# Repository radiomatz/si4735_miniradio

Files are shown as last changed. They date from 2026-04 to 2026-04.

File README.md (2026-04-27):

# si4735_miniradio
SI4735-D60 Circuit and Arduino Sketech for Building a SW/FM Radio with 150kHz..30MHz AM/SSB + 64-108MHz FM

<img src="pics/testcircuit.jpg>

### used Hardware
- Atmega 328P-PU with its internal 8 MHz
- SI4735-D60-GU
- LM386 Dip
- LM1117 3.3 Volts
- SMD Capacitors all 0805
- Elkos all tht, mnost low profile or layed flat
- Quartz 32k Clock Crystal

### Software needed
- Arduino Studio Version 2
- addon for MiniCore (support for single 328 Chips)
- tiny4k oled library and (6x8) font package

### some details
- i am using a 7.2V LiPo, which is directly connencted to the lm386 - it can have about 5-12V
- the mcu and the radio chip SI4735-D60-GU is driven with a LM1117-3.3 with 3.3V, that is important for the SI4735, and enough for an ATMEGA328

### some modifications (which will be in v2 circuit) are made after this circuit(v1):

- add a reset knob between pin 1 of atmega328-pu and gnd for programming from outside.
- insert a 1k2 resistor between pin 1 of lm386 and the 10µ c at pin 8, because gain of 50 is enough.
- my first circuit (the one with the case) i used sockets and plugs for programming outside, but i recommend to solder the AT328 directly and dont use the plugs on the circuit, instead use direct wires for getting more place in the case. Also i used another CA5 

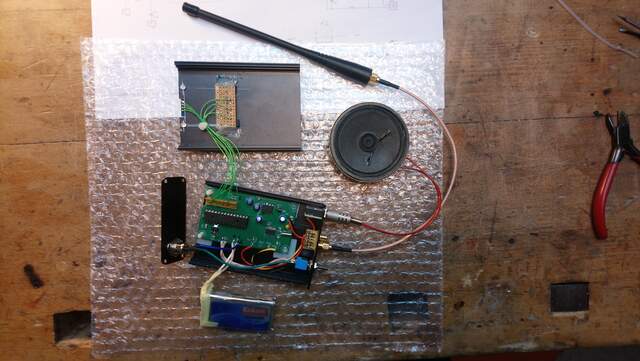
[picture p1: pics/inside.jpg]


### hints for using
- left button is "down", middle button is "mode", right button is "up"
- you have a preview of the mode right of the mode which has the star in front.
- frequency display has as suffix its step with a slash, also bfo 
- to lock, press up or down in lock mode; to unlock, use up and down simultaneous

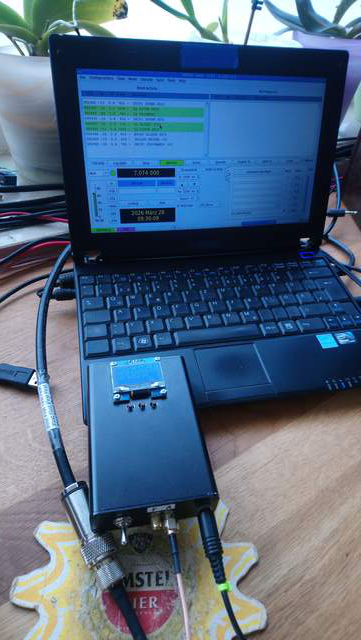
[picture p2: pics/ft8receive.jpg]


if you have any questions, feel free to ask me: dm2hr@darc.de

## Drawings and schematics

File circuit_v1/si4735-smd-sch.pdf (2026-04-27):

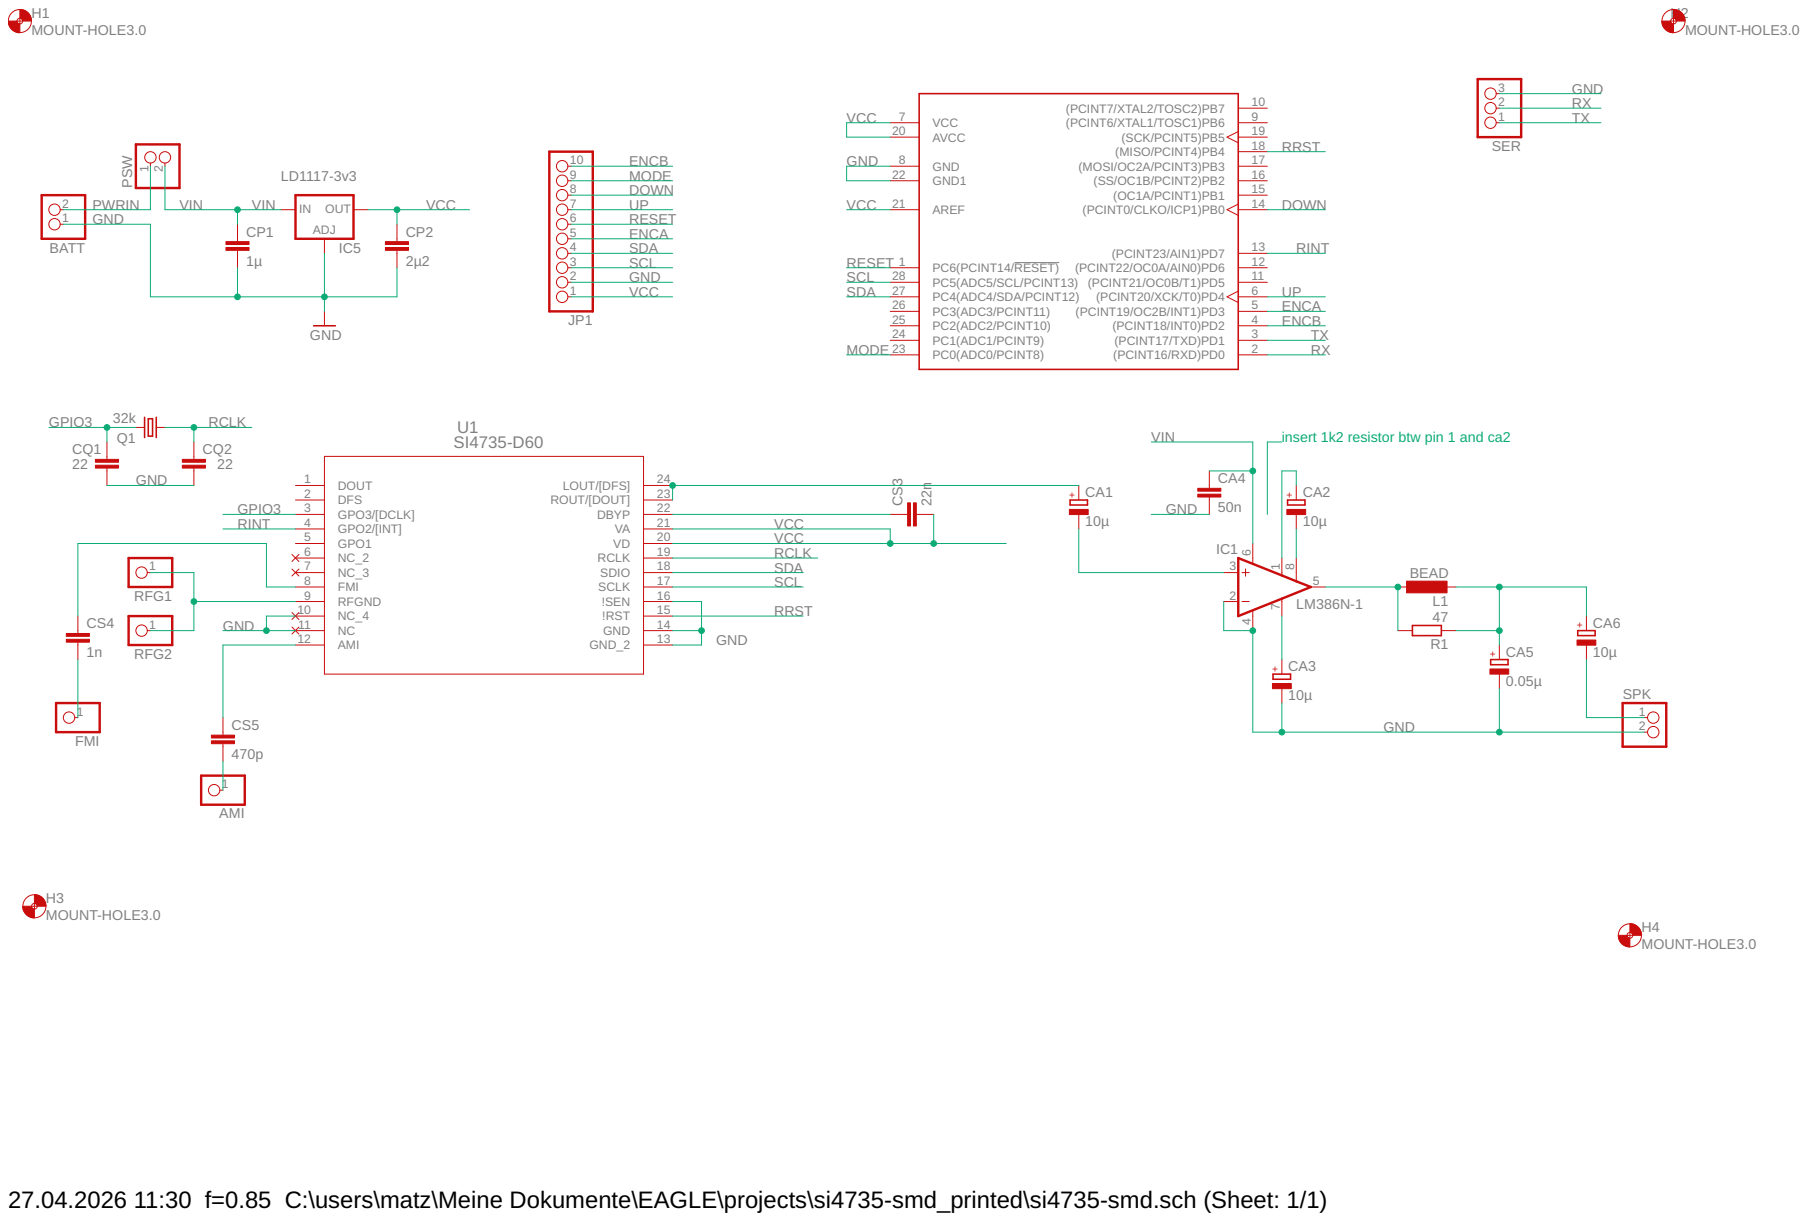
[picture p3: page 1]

insert 1k2 resistor btw pin 1 and ca2

27.04.2026 11:30 f=0.85 C:\users\matz\Meine Dokumente\EAGLE\projects\si4735-smd_printed\si4735-smd.sch (Sheet: 1/1)

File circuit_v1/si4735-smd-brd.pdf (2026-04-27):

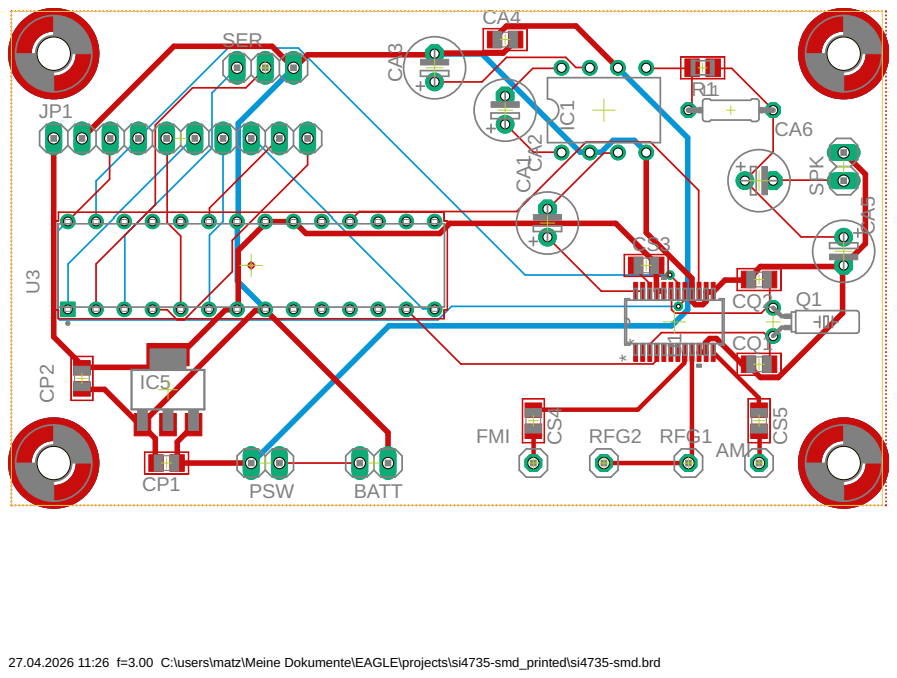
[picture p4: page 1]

27.04.2026 11:26 f=3.00 C:\users\matz\Meine Dokumente\EAGLE\projects\si4735-smd_printed\si4735-smd.brd

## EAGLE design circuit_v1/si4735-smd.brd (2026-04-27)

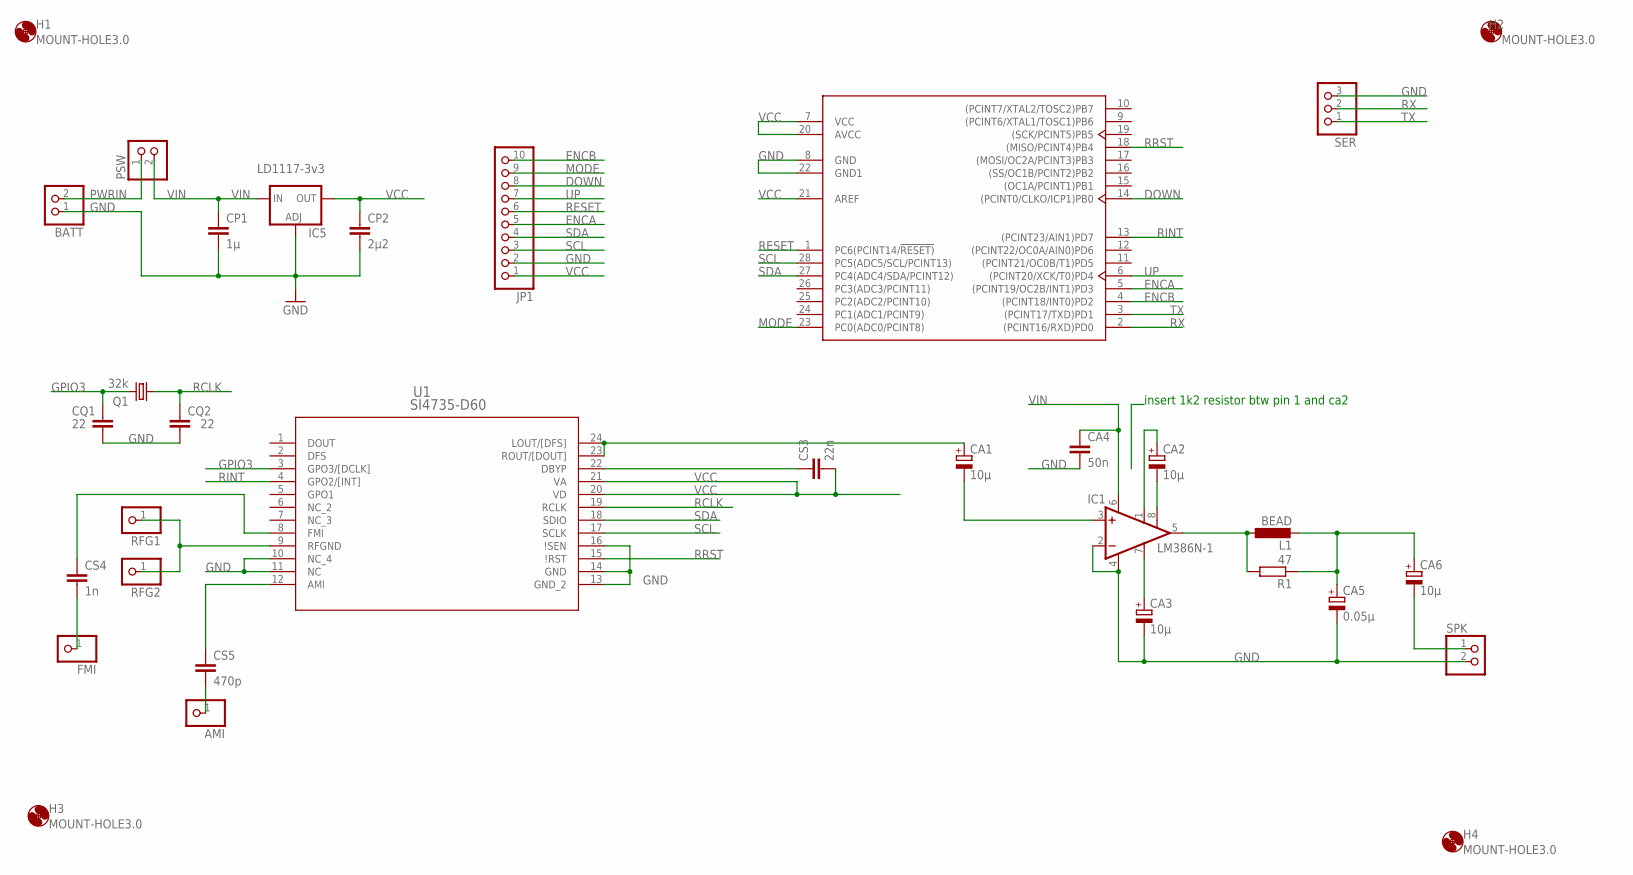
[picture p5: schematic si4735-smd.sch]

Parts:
AMI: PINHD-1X1; 1X01
BATT: PINHD-1X2; 1X02
CA1, CA2, CA3, CA6: 10µ; E2,5-6
CA4: 50n; C0805
CA5: 0.05µ; E2,5-6
CP1: 1µ; C0805
CP2: 2µ2; C0805
CQ1, CQ2: 22; C0805
CS3: 22n; C0805
CS4: 1n; C0805
CS5: 470p; C0805
FMI: PINHD-1X1; 1X01
H1, H2, H3, H4: MOUNT-HOLE3.0; 3,0
IC1: LM386N-1; DIL08
IC5: LD1117-3v3; SOT223
JP1: PINHD-1X10; 1X10
L1: BEAD; 0204/7
PSW: PINHD-1X2; 1X02
Q1: 32k; TC26H
R1: 47; M0805
RFG1, RFG2: PINHD-1X1; 1X01
SER: PINHD-1X3; 1X03
SPK: PINHD-1X2; 1X02
U1: SI4735-D60; SSOP24_SIL-M
U3: ATMEGA328P-PU; DIP-28

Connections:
DOWN: JP1.8, U3.14 ((PCINT0/CLKO/ICP1)PB0)
ENCA: JP1.5, U3.5 ((PCINT19/OC2B/INT1)PD3)
ENCB: JP1.10, U3.4 ((PCINT18/INT0)PD2)
GND: BATT.1, CA3.-, CA4.2, CA5.-, CP1.2, CP2.2, CQ1.2, CQ2.2, IC1.2 (-IN), IC1.4 (GND), IC5.1 (ADJ), JP1.2, SER.3, SPK.2, U1.10 (NC_4), U1.11 (NC), U1.13 (GND_2), U1.14 (GND), U1.16 (\!SEN), U3.8 (GND), U3.22 (GND1)
GPIO3: CQ1.1, Q1.2, U1.3 (GPO3/[DCLK])
MODE: JP1.9, U3.23 (PC0(ADC0/PCINT8))
unnamed: CA1.+, U1.23 (ROUT/[DOUT]), U1.24 (LOUT/[DFS])
unnamed: CA1.-, IC1.3 (+IN)
unnamed: CA2.+, IC1.1 (GAIN)
unnamed: CA2.-, IC1.8 (GAIN)
unnamed: IC1.5 (OUT), L1.1, R1.2
unnamed: CA5.+, CA6.+, L1.2, R1.1
unnamed: CA6.-, SPK.1
unnamed: CA3.+, IC1.7 (BYPASS)
unnamed: RFG1.1, RFG2.1, U1.9 (RFGND)
unnamed: CS4.1, U1.8 (FMI)
unnamed: CS4.2, FMI.1
unnamed: CS3.1, U1.22 (DBYP)
unnamed: CS5.1, U1.12 (AMI)
unnamed: AMI.1, CS5.2
PWRIN: BATT.2, PSW.1
RCLK: CQ2.1, Q1.1, U1.19 (RCLK)
RESET: JP1.6, U3.1 (PC6(PCINT14/!RESET))
RINT: U1.4 (GPO2/[INT]), U3.13 ((PCINT23/AIN1)PD7)
RRST: U1.15 (\!RST), U3.18 ((MISO/PCINT4)PB4)
RX: SER.2, U3.2 ((PCINT16/RXD)PD0)
SCL: JP1.3, U1.17 (SCLK), U3.28 (PC5(ADC5/SCL/PCINT13))
SDA: JP1.4, U1.18 (SDIO), U3.27 (PC4(ADC4/SDA/PCINT12))
TX: SER.1, U3.3 ((PCINT17/TXD)PD1)
UP: JP1.7, U3.6 ((PCINT20/XCK/T0)PD4)
VCC: CP2.1, CS3.2, IC5.4 (OUT), JP1.1, U1.20 (VD), U1.21 (VA), U3.7 (VCC), U3.20 (AVCC), U3.21 (AREF)
VIN: CA4.1, CP1.1, IC1.6 (VS), IC5.3 (IN), PSW.2

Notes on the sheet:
insert 1k2 resistor btw pin 1 and ca2

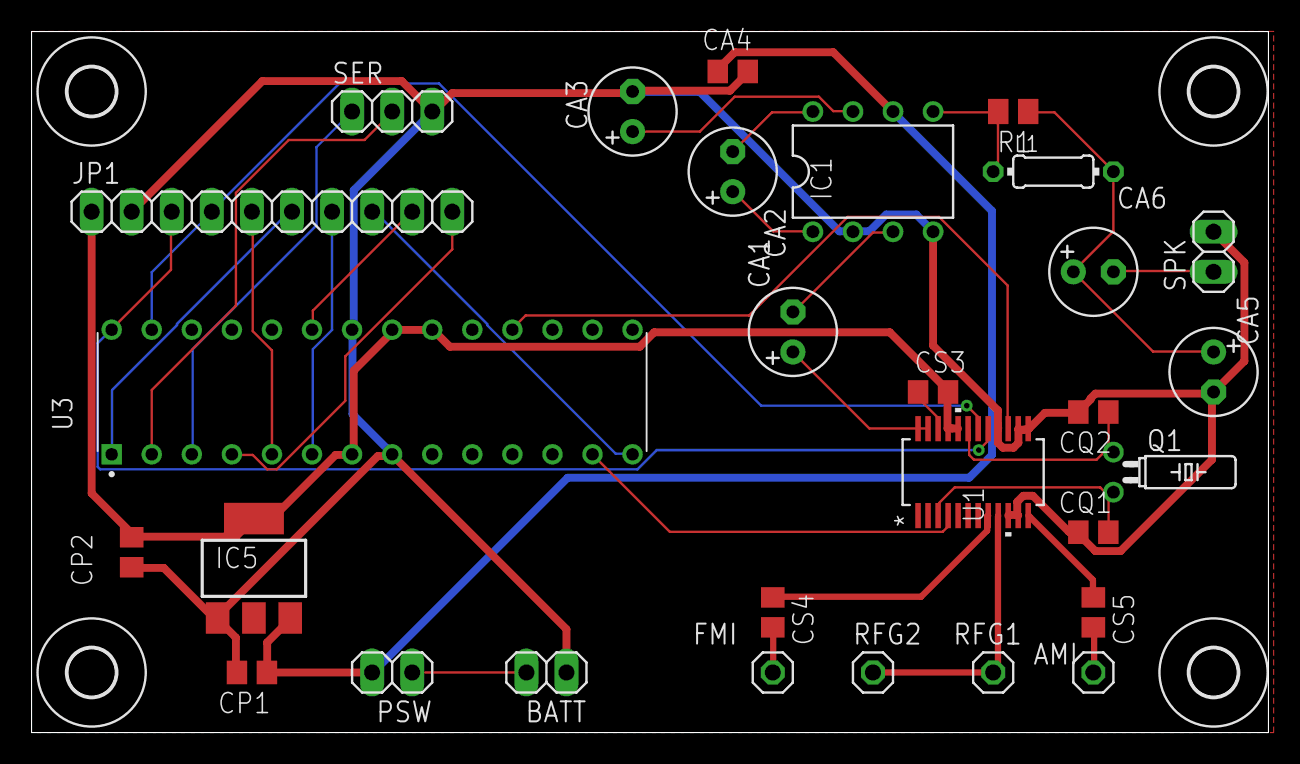
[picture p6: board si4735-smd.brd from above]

Board: 2 copper layers, 78.4 x 44.4 mm, 33 parts (0 on the bottom side), 32 nets.

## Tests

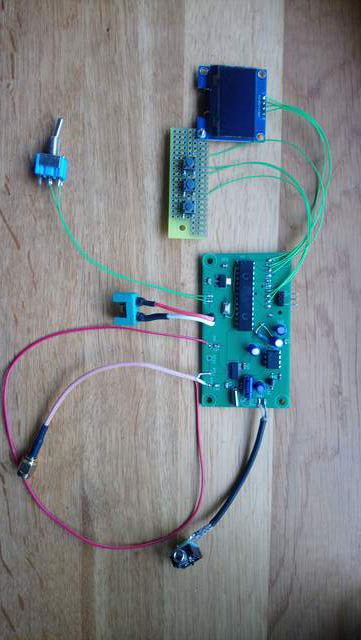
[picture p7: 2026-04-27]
pics/testcircuit.jpg

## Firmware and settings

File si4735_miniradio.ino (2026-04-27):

#include "SI4735.h"
#include <EEPROM.h>

#include <Tiny4kOLED.h>

/*
 * Modified from PU2CLR's SI473x Library example for Arduino
 * this Variant is from Matthias, DM2HR
 * my Circuit can be found at https:///github.com/radiomatz/si4735_miniradio
 * Dependencies:
 *  - (modified) SI4735 Library of PU2CLR (included here)
 * - Tiny4kOled
 * - Tiny4koled font 6x8
 */

#define SH1106       // or #undef SH1106, when using a SSD1306 Display
#undef ROTARY_ENABLE // if you want to youse a Rotary like in the original Example
#undef SERIAL_ENABLE // if you want to try out some things on serial line

#ifdef ROTARY_ENABLE
#include "Rotary.h"
#endif

#include "patch_ssb_compressed.h"  // Compressed SSB patch version (saving almost 1KB)

const uint16_t size_content = sizeof ssb_patch_content;  // See ssb_patch_content.h
const uint16_t cmd_0x15_size = sizeof cmd_0x15;          // Array of lines where the 0x15 command occurs in the patch content.

#define FM_BAND_TYPE 0
#define MW_BAND_TYPE 1
#define SW_BAND_TYPE 2
#define LW_BAND_TYPE 3

// OLED Diaplay constants
#define RST_PIN -1  // Define proper RST_PIN if required.

#define RESET_PIN 12  // of si4735
#define GPIOINTPIN 7  // of si4735
#ifdef ROTARY_ENABLE
// Enconder PINs - if the clockwise and counterclockwise directions are not correct for you, please, invert this settings.
#define ENCODER_PIN_A 3
#define ENCODER_PIN_B 2
#endif

// CMD Buttons
#define BUTTON A0            // cmd switch button
#define BUTTONONESTEPUP 4    // instead of rotary: encoderCount = +1
#define BUTTONONESTEPDOWN 8  // instead of rotary: encoderCount = -1

#define MIN_ELAPSED_TIME 500
#define MIN_ELAPSED_RSSI_TIME 1500

#define DEFAULT_VOLUME 25  // change it for your favorite sound volume

#define FM 0
#define LSB 1
#define USB 2
#define AM 3
#define LW 4
const char *bandModeDesc[] = { "FM ", "LSB", "USB", "AM ", "LW " };


// EEPROM Constants
#define STORE_TIME 10000  // Time of inactivity to make the current receiver status writable (10s / 10000 milliseconds).
#define IDARR 44          // ID of saved Arr in EEPROM
// EEPROM Locations
#define IDNRLOC 0     // Idnr for this Prog
#define DEFECTCELL 1  // sadly, here
#define IDXLOC 2      // BandIdx
#define CMDADR 3      // "cursor" of cmdlist
#define VOLADR 4      // Volume
// some room for more ...
#define SAVEADR 10  // location of BandArray in EEPROM



bool locksave = false;
uint8_t i = 0;

long storeTime = millis();

uint8_t currentMode = FM;
uint8_t seekDirection = 1;

uint8_t amSoftMuteThr = 0;

bool bfoOn = false;
bool avc_en = true;

bool ssbLoaded = false;
bool fmStereo = false;

bool cmdVolume = false;  // if true, the encoder will control the volume.
bool cmdAgcAtt = false;  // if true, the encoder will control the AGC / Attenuation
bool cmdStep = false;    // if true, the encoder will control the step frequency
bool cmdBw = false;      // if true, the encoder will control the bandwidth
bool cmdBand = false;    // if true, the encoder will control the band

long countRSSI = 0;

int currentBFO = 0;

long elapsedRSSI = millis();
long elapsedButton = millis();

// Encoder control variables
volatile int encoderCount = 0;
volatile bool bModeButton = false;

// Some variables to check the SI4735 status
uint16_t currentFrequency;
uint16_t newfreq;
uint16_t previousFrequency;
// uint8_t currentStep = 1;
uint8_t currentBFOStep = 25;

bool updateOled = true;

// Datatype to deal with bandwidth on AM, SSB and FM in numerical order.
// Ordering by bandwidth values.
typedef struct {
  uint8_t idx;       // SI473X device bandwidth index value
  const char *desc;  // bandwidth description
} Bandwidth;

int8_t bwIdxSSB = 4;
Bandwidth bandwidthSSB[] = {
  { 4, "0.5" },  // 0
  { 5, "1.0" },  // 1
  { 0, "1.2" },  // 2
  { 1, "2.2" },  // 3
  { 2, "3.0" },  // 4  - default
  { 3, "4.0" }   // 5
};

int8_t bwIdxAM = 5;
const int maxFilterAM = 6;
Bandwidth bandwidthAM[] = {
  { 4, "1.0" },  // 0
  { 5, "1.8" },  // 1
  { 3, "2.0" },  // 2
  { 6, "2.5" },  // 3
  { 2, "3.0" },  // 4 - default
  { 1, "4.0" },  // 5
  { 0, "6.0" }   // 6
};

int8_t bwIdxFM = 0;
Bandwidth bandwidthFM[] = {
  { 0, "AUT" },  // Automatic - default
  { 1, "110" },  // Force wide (110 kHz) channel filter.
  { 2, " 84" },
  { 3, " 60" },
  { 4, " 40" }
};

// Atenuação and AGC
int8_t agcIdx = 0;
uint8_t disableAgc = 0;
uint8_t agcNdx = 0;

int tabStep[] = {
  1,    // 0
  5,    // 1
  9,    // 2
  10,   // 3
  50,   // 4
  100,  // 5
  500
};

const int lastStep = (sizeof tabStep / sizeof(int)) - 1;
int idxStep = 1;


typedef struct {
  uint8_t bandType;        // Band type (FM, MW or SW)
  uint16_t minimumFreq;    // Minimum frequency of the band
  uint16_t maximumFreq;    // maximum frequency of the band
  uint16_t currentFreq;    // Default frequency or current frequency
  uint8_t currentStepIdx;  // Idex of tabStep:  Defeult frequency step (See tabStep)
  uint8_t bandwidthIdx;    //  Index of the table bandwidthFM, bandwidthAM or bandwidthSSB;
  char banddesc[4];
  int16_t bfo;
  uint8_t mode;
} Band;

Band band[] = {
  { FM_BAND_TYPE, 6400, 10800, 9850, 3, 5, "FM", 0, FM },    // Bayern 3
  { FM_BAND_TYPE, 6400, 10800, 9070, 3, 5, "B1", 0, FM },    // Bayern 1
  { FM_BAND_TYPE, 6400, 10800, 10000, 3, 5, "DLF", 0, FM },  // Deutschlandfunk
  { LW_BAND_TYPE, 149, 520, 225, 2, 5, "LW", 0, AM },
  { MW_BAND_TYPE, 520, 1810, 530, 2, 5, "MW", 0, AM },
  { SW_BAND_TYPE, 1810, 30000, 9670, 0, 5, "DAR", 0, AM },  // Radio DARC, Sun, 11:00 Localtime Germany
  { SW_BAND_TYPE, 1810, 30000, 6180, 0, 5, "DWD", 0, AM },  // DWD Voice Pinneberg
  { SW_BAND_TYPE, 1810, 30000, 1840, 0, 5, "FT8", 0, USB },
  { SW_BAND_TYPE, 1810, 30000, 3573, 0, 5, "FT8", 0, USB },
  { SW_BAND_TYPE, 1810, 30000, 5364, 0, 2, "WSP", -401, USB },
  { SW_BAND_TYPE, 1810, 30000, 7074, 0, 5, "FT8", 0, USB },
  { SW_BAND_TYPE, 1810, 30000, 10136, 0, 5, "FT8", 0, USB },
  { SW_BAND_TYPE, 1810, 30000, 14074, 0, 5, "FT8", 0, USB },
  { SW_BAND_TYPE, 1810, 30000, 18100, 0, 5, "FT8", 0, USB },
  { SW_BAND_TYPE, 1810, 30000, 21074, 0, 5, "FT8", 0, USB },
  { SW_BAND_TYPE, 1810, 30000, 24915, 0, 5, "FT8", 0, USB },
  { SW_BAND_TYPE, 1810, 30000, 28074, 0, 5, "FT8", 0, USB },
  { SW_BAND_TYPE, 1810, 30000, 3855, 0, 3, "DWD", 1050, USB },   // DDH3 DWD WeFax IOC576
  { SW_BAND_TYPE, 1810, 30000, 7880, 0, 3, "DWD", 1225, USB },   // DDK3 DWD WeFax IOC576
  { SW_BAND_TYPE, 1810, 30000, 4583, 0, 1, "DWD", 1280, USB },   // DDK2 DWD Rtty 50Bd 450Hz
  { SW_BAND_TYPE, 1810, 30000, 7646, 0, 1, "DWD", 1427, USB },   // DDH7 DWD Rtty 50Bd 450Hz
  { SW_BAND_TYPE, 1810, 30000, 10100, 0, 1, "DWD", 835, USB },   // DDK9 DWD Rtty 50Bd 450Hz
  { SW_BAND_TYPE, 1810, 30000, 149, 0, 0, "DWD", 2225, USB },    // DDH47 DWD Rtty 50Bd _85Hz_(147.3kHz)
  { SW_BAND_TYPE, 1810, 30000, 11039, 0, 1, "DWD", 1440, USB },  // DDH9 DWD Rtty 50Bd 450Hz
  { SW_BAND_TYPE, 1810, 30000, 14230, 0, 3, "TV1", 600, USB },   // SSTV
  { SW_BAND_TYPE, 1810, 30000, 21340, 0, 3, "TV2", 600, USB },   // SSTV
  { SW_BAND_TYPE, 1810, 30000, 28680, 0, 3, "TV3", 600, USB },   // SSTV
  { SW_BAND_TYPE, 1810, 30000, 27245, 1, 5, "CB", 0, USB },      // SSTV
  { SW_BAND_TYPE, 1810, 30000, 1885, 0, 5, "Swa", 0, LSB },      // Schwaben Rundspruch DARC Dok T05
  { SW_BAND_TYPE, 1810, 30000, 3590, 0, 5, "Obb", -750, USB },   // Oberbayern Rundspruch DARC Dok C digital MFSK-32 Center 750 Hz
  { SW_BAND_TYPE, 1810, 30000, 15350, 1, 5, "Tye", 0, AM },      // Stimme Türkiye
  { SW_BAND_TYPE, 1810, 30000, 11880, 1, 5, "RO", 0, AM },       // Radio Romania
  { SW_BAND_TYPE, 1810, 30000, 9535, 6, 5, "CN1", 0, AM },       // Chinese
  { SW_BAND_TYPE, 1810, 30000, 11735, 6, 5, "CN2", 0, AM }       // Chinese
};

const uint8_t lastBand = (sizeof band / sizeof(Band)) - 1;
uint8_t bandIdx = 1;

uint8_t rssi = 0;
uint8_t stereo = 1;
uint8_t volume = DEFAULT_VOLUME;

// Devices class declarations
#ifdef ROTARY_ENABLE
Rotary encoder = Rotary(ENCODER_PIN_A, ENCODER_PIN_B);
#endif

SI4735 si4735;

bool key_reset = false;
char key = 0;
char *stationName;
char bufferStatioName[20];
long rdsElapsed = millis();
char oldBuffer[15];


#define CMDTABSIZE 12
enum {
  CMDSTEP,
  CMDFREQ,
  CMDVOL,
  CMDMODE,
  CMDBAND,
  CMDBFOSTEP,
  CMDBFO,
  CMDAGC,
  CMDVC,
  CMDBW,
  CMDSEEK,
  CMDLOCK
} CMDTAB;
const char *CMDTABSTR[CMDTABSIZE] = { "STEP", "FREQ", "VOL", "MODE", "BAND", "BSTEP", "BFO", "AGC", "VC", "BW", "SEEK", "LOCK" };
uint8_t cmd = 0;

// *****************************************************************

void setup() {

#ifdef SERIAL_ENABLE
  Serial.begin(115200);
  delay(500);
  if (Serial.available() && Serial.read() == 'r')
    key_reset = true;
#endif  // SERIAL_ENABLE

    // Encoder pins
#ifdef ROTARY_ENABLE
  pinMode(ENCODER_PIN_A, INPUT_PULLUP);
  pinMode(ENCODER_PIN_B, INPUT_PULLUP);
#endif

  pinMode(BUTTON, INPUT_PULLUP);
  pinMode(BUTTONONESTEPUP, INPUT_PULLUP);
  pinMode(BUTTONONESTEPDOWN, INPUT_PULLUP);

  // Splash - Change it for your introduction text.
#ifdef SERIAL_ENABLE
  Serial.println(F("SI4735-D60 by DM2HR"));
  Serial.println(F("All in One Radio"));
  Serial.println(F("Arduino Library -"));
  Serial.println(F("V3.0.7 - By PU2CLR"));

  Serial.println(F("Init OLED now..."));
#endif

#ifdef SH1106
  oled.begin(2, 0, 128, 64, sizeof(tiny4koled_init_128x32r), tiny4koled_init_128x32r);
#else
  oled.begin();
#endif
  oled.clear();
  oled.on();
  oled.setFont(FONT6X8);
  oled.setContrast(255);

  oled.println(F("SI4735-D60 by DM2HR"));
  oled.println(F("All in One Radio"));
  oled.println(F("Arduino Library -"));
  oled.print(F("V3.0.7 - By PU2CLR"));

  delay(500);

  // If you want to reset the eeprom, keep the VOLUME_UP button pressed during statup
  if (digitalRead(BUTTON) == LOW || key_reset) {

    oled.clear();
    oled.print(F("EEPROM RESET"));
    for (int j = 0; j < EEPROM.length(); j++) {
      oled.setCursor(0, 1);
      EEPROM.write(j, 0xff);
      oled.print(j);
    }
    // delay(2000);
    oled.clear();
  }

  // Encoder interrupt
#ifdef ROTARY_ENABLE
  attachInterrupt(digitalPinToInterrupt(ENCODER_PIN_A), rotaryEncoder, CHANGE);
  attachInterrupt(digitalPinToInterrupt(ENCODER_PIN_B), rotaryEncoder, CHANGE);
#endif  // ROTARY_ENABLE

  // Gets and sets the Si47XX I2C bus address
  int16_t si4735Addr = si4735.getDeviceI2CAddress(RESET_PIN);
  if (si4735Addr == 0) {
#ifdef SERIAL_ENABLE
    Serial.println(F("Si473X not found!"));
    Serial.flush();
#else
    oled.clear();
    oled.print(F("Si473X not found!!"));
#endif
    while (1)
      ;
  } else {
#ifdef SERIAL_ENABLE
    Serial.print(F("The Si473X I2C address is 0x"));
    Serial.println(si4735Addr, HEX);
#endif
  }

  si4735.setup(RESET_PIN, MW_BAND_TYPE);  //
  delay(300);

  // Checking the EEPROM content
  if (EEPROM.read(IDNRLOC) == IDARR) {
    readAllReceiverInformation();
  }

  // Set up the radio for the current band (see index table variable bandIdx )
  currentMode = band[bandIdx].mode;
  check_loadpatch();
  useBand();

  currentFrequency = previousFrequency = si4735.getFrequency();
  si4735.setAvcAmMaxGain(90);  // Sets the maximum gain for automatic volume control on AM/SSB mode (from 12 to 90dB)
  delay(50);

#ifdef SERIAL_ENABLE
  Serial.print(F("set Volume to: "));
  Serial.println(volume);
#endif
  si4735.setVolume(volume);
  delay(50);
}

// *****************************************************************

void check_loadpatch() {
  if (currentMode == USB || currentMode == LSB) {
    if (!ssbLoaded)
      loadSSB();
    currentBFO = band[bandIdx].bfo;
    si4735.setSSBBfo(currentBFO);
  } else {
    if (currentMode != FM)
      currentMode = AM;
    ssbLoaded = false;
    bfoOn = false;
    useBand();
  }
}

// *****************************************************************

// ISR's
#ifdef ROTARY_ENABLE
void rotaryEncoder() {
  static uint8_t encoderStatus = encoder.process();
  if (encoderStatus) {
    if (encoderStatus == DIR_CW) {
      encoderCount = 1;
    } else {
      encoderCount = -1;
    }
  }
}
#endif

// *****************************************************************

/* EEPROM Routines */
void saveAllReceiverInformation() {
  writeEpromState();
#ifdef SERIAL_ENABLE
  Serial.println(F("State saved in EEPROM"));
#endif
}

void writeEpromState() {
  if (locksave)
    return;
  locksave = true;

#ifdef SERIAL_ENABLE
  Serial.println(F("write EEPROM"));
#endif
  uint8_t *ptr = (uint8_t *)&band;
  EEPROM.update(IDNRLOC, IDARR);
  EEPROM.update(IDXLOC, bandIdx);
  EEPROM.update(VOLADR, volume);
  EEPROM.update(CMDADR, (uint8_t)cmd);
  for (int i = 0; i < sizeof(band); i++) {
    EEPROM.update(SAVEADR + i, *(ptr + i));
  }
  resetEepromDelay();
  locksave = false;
}

void readAllReceiverInformation() {
  readEpromState();
#ifdef SERIAL_ENABLE
  Serial.println(F("EEPROM State restored"));
#endif
}

void readEpromState() {
#ifdef SERIAL_ENABLE
  Serial.println(F("read EEPROM"));
#endif
  uint8_t *ptr = (uint8_t *)&band;
  for (int i = 0; i < sizeof(band); i++) {
    *(ptr + i) = EEPROM.read(SAVEADR + i);
  }
  EEPROM.get(IDXLOC, bandIdx);
  EEPROM.get(VOLADR, volume);
#ifdef SERIAL_ENABLE
  Serial.print(F("EEPROM volume:"));
  Serial.println(volume);
#endif
  EEPROM.get(CMDADR, cmd);
}

void resetEepromDelay() {
  storeTime = millis();
  previousFrequency = 0;
}

// *****************************************************************
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
void loop() {

#ifdef SERIAL_ENABLE

  if (Serial.available()) {
    key = Serial.read();
    switch (key) {
      case '0':
      case '1':
      case '2':
      case '3':
      case '4':
      case '5':
      case '6':
      case '7':
      case '8':
      case '9':
        newfreq = (newfreq * 10) + (key - '0');
        Serial.print(F("\rNew Frequency: "));
        Serial.print(newfreq);
        break;

      case '\b':
        newfreq = newfreq / 10;
        Serial.print(F("New Frequency: "));
        Serial.println(newfreq);
        break;

      case 0x0d:
      case 0x0a:
        Serial.println();
        if (newfreq == 0)
          break;
        si4735.setFrequencyReliable(newfreq);
        currentFrequency = si4735.getFrequency();
        if (currentFrequency != 0)
          band[bandIdx].currentFreq = currentFrequency;
        newfreq = 0;
        Serial.print(F("Switch Frequency: "));
        Serial.println(currentFrequency);
        previousFrequency = 0;
        break;

      case 'v':
        encoderCount = -1;
        cmd = CMDVOL;
        break;

      case 'V':
        encoderCount = 1;
        cmd = CMDVOL;
        break;

      case 'a':
        encoderCount = -1;
        cmd = CMDAGC;
        break;

      case 'A':
        encoderCount = 1;
        cmd = CMDAGC;
        break;

      case 's':
        encoderCount = 1;
        cmd = CMDSTEP;
        break;

      case 'w':
        encoderCount = -1;
        cmd = CMDBW;
        break;

      case 'W':
        encoderCount = 1;
        cmd = CMDBW;
        break;

      case 'm':
        encoderCount = 1;
        cmd = CMDMODE;
        break;

      case 'r':
        Serial.print(F("RDS Station:"));
        Serial.println(stationName);
        break;

      case 'B':
        encoderCount = 1;
        cmd = CMDBFO;
        break;

      case 'b':
        encoderCount = -1;
        cmd = CMDBFO;
        break;

      case '<':
        encoderCount = -1;
        cmd = CMDBAND;
        break;

      case '>':
        encoderCount = 1;
        cmd = CMDBAND;
        break;

      case 'x':
        break;

      case ',':
      case '.':
        if (currentMode == FM || currentMode == AM) {
          cmd = CMDSEEK;
          if (key == '.')
            encoderCount = 1;
          else
            encoderCount = -1;
        }
        break;

      case '-':
        encoderCount = -1;
        cmd = CMDFREQ;
        break;

      case '+':
        encoderCount = 1;
        cmd = CMDFREQ;
        break;
    }
    showStatus();
    showOledStatus();
  }
#endif  // SERIAL_ENABLE

  if (!locksave) {
    // BUTTIONS
    if (digitalRead(BUTTON) == LOW) {
      while (digitalRead(BUTTON) == LOW) delay(1);
      updateOled = true;
      cmd++;
      if (cmd >= CMDTABSIZE)
        cmd = 0;
      showCmdMode();
    }
    if (digitalRead(BUTTONONESTEPUP) == LOW) {
      while (digitalRead(BUTTONONESTEPUP) == LOW) delay(1);
      encoderCount = 1;
    } else if (digitalRead(BUTTONONESTEPDOWN) == LOW) {
      while (digitalRead(BUTTONONESTEPDOWN) == LOW) delay(1);
      encoderCount = -1;
    }
  } else {
    if (digitalRead(BUTTONONESTEPUP) + digitalRead(BUTTONONESTEPDOWN) == LOW) {
      while (digitalRead(BUTTONONESTEPUP) + digitalRead(BUTTONONESTEPDOWN) == LOW)
        delay(1);
      locksave = false;
      showCmdMode();
    }
  }


  // Check if the encoder has moved.
  if (encoderCount != 0) {
    updateOled = true;

    switch (cmd) {
      case CMDFREQ:
        if (encoderCount == 1) {
          si4735.frequencyUp();
          seekDirection = 1;
        }
        if (encoderCount == -1) {
          si4735.frequencyDown();
          seekDirection = 0;
        }
        currentFrequency = si4735.getFrequency();
        if (currentFrequency != 0)
          band[bandIdx].currentFreq = currentFrequency;
        previousFrequency = 0;
        break;

      case CMDSTEP:
        doStep(encoderCount);
        break;

      case CMDVOL:
        doVolume(encoderCount);
        break;

      case CMDBAND:
        if (encoderCount == 1)
          bandUp();
        if (encoderCount == -1)
          bandDown();
        currentMode = band[bandIdx].mode;
        check_loadpatch();
        break;

      case CMDAGC:
        doAgcAtt(encoderCount);
        break;

      case CMDBFO:
        currentBFO = (encoderCount == 1) ? (currentBFO + currentBFOStep) : (currentBFO - currentBFOStep);
        si4735.setSSBBfo(currentBFO);
        band[bandIdx].bfo = currentBFO;
        previousFrequency = 0;  // Forces eeprom update
        break;

      case CMDBFOSTEP:
        if (currentBFOStep == 1)
          currentBFOStep = 5;
        else if (currentBFOStep == 5)
          currentBFOStep = 10;
        else if (currentBFOStep == 10)
          currentBFOStep = 25;
        else if (currentBFOStep == 25)
          currentBFOStep = 50;
        else if (currentBFOStep == 50)
          currentBFOStep = 100;
        else if (currentBFOStep == 100)
          currentBFOStep = 250;
        else if (currentBFOStep == 250)
          currentBFOStep = 1;
        break;

      case CMDBW:
        doBandwidth(encoderCount);
        break;

      case CMDMODE:
        if (currentMode == AM) {
          // If you were in AM mode, it is necessary to load SSB patch (avery time)
          loadSSB();
          currentMode = LSB;
          currentBFO = band[bandIdx].bfo;
          si4735.setSSBBfo(currentBFO);
        } else if (currentMode == LSB) {
          currentMode = USB;
          currentBFO = band[bandIdx].bfo;
          si4735.setSSBBfo(currentBFO);
        } else if (currentMode == USB) {
          currentMode = AM;
          ssbLoaded = false;
          bfoOn = false;
        }
        if (currentFrequency != 0)
          band[bandIdx].currentFreq = currentFrequency;
        band[bandIdx].currentStepIdx = idxStep;
        band[bandIdx].mode = currentMode;
        useBand();
        break;

      case CMDVC:
        avc_en = avc_en == 0 ? 1 : 0;
        if (ssbLoaded) {
          si4735.setSSBAutomaticVolumeControl(avc_en);
        } else {  // TODO
          // si4735.setAutomaticVolumeControl(avc_en);
        }
        break;

      case CMDSEEK:
        if (currentMode == FM || currentMode == AM) {
          if (encoderCount == 1)
            seekDirection = 1;
          else
            seekDirection = 0;
          /* old method of PU2CLR */
          // Jumps up or down one space
          if (seekDirection)
            si4735.frequencyUp();
          else
            si4735.frequencyDown();
          si4735.seekStationProgress(showFrequencySeek, checkStopSeeking, seekDirection);
          delay(30);
          if (currentMode == FM) {
            float f = round(si4735.getFrequency() / 10.0);
            currentFrequency = (uint16_t)f * 10;  // adjusts band space from 1 (10kHz) to 10 (100 kHz)
            si4735.setFrequencyReliable(currentFrequency);
          } else {
            currentFrequency = si4735.getFrequency();  //
          }
          if (currentFrequency != 0)
            band[bandIdx].currentFreq = currentFrequency;

          previousFrequency = 0;
        }
        break;

      case CMDLOCK:
        locksave = true;
        showCmdMode();
        break;
    }

    if (encoderCount != 0) {
      showStatus();
      updateOled = true;
    }

    encoderCount = 0;
    resetEepromDelay();  // if you moved the encoder, something was changed
    elapsedRSSI = millis();
    countRSSI = 0;
    elapsedButton = millis();
  }

  // Show RSSI status only if this condition has changed
  if ( (millis() - elapsedRSSI) > MIN_ELAPSED_RSSI_TIME * 9 ) {
    si4735.getCurrentReceivedSignalQuality();
    int aux = si4735.getCurrentRSSI();
    if (rssi != aux) {
      rssi = aux;
      showStatus();
      updateOled = true;
    }


    if (countRSSI++ > 3) {
      //disableCommand(NULL, false, NULL); // disable all command buttons
      countRSSI = 0;
    }
    elapsedRSSI = millis();
  }

  if (currentMode == FM) {
    if (currentFrequency != previousFrequency) {
      cleanBfoRdsInfo();
    } else {
      checkRDS();
    }
  }

  if ( updateOled ) {
    updateOled = false;
    showOledStatus();
  }

  // Show the current frequency only if it has changed
  if ((currentFrequency != previousFrequency && currentFrequency != 0)
      || (millis() - storeTime) > STORE_TIME) {
    band[bandIdx].currentFreq = currentFrequency;
    saveAllReceiverInformation();
    storeTime = millis();
    previousFrequency = currentFrequency;
    // updateOled = true;
  }
  delay(1);
}

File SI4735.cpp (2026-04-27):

/**
 * @mainpage SI47XX Arduino Library implementation 
 * 
 * This is a library for the SI4735, BROADCAST AM/FM/SW RADIO RECEIVER, IC from Silicon Labs for the 
 * Arduino development environment.  It works with I2C protocol and can provide an easier interface for controlling the SI47XX CI family.<br>
 * 
 * This library was built based on [Si47XX PROGRAMMING GUIDE-AN332 (REV 1.0)](https://www.silabs.com/documents/public/application-notes/AN332.pdf) document from Silicon Labs. 
 *
 * It also can be used on **all members of the SI473X family** respecting, of course, the features available for each IC version. 
 * These functionalities can be seen in the comparison matrix shown in table 1 (Product Family Function); pages 2 and 3 of the programming guide.
 * If you need to build a prototype based on SI47XX device, see <https://pu2clr.github.io/SI4735/><br>
 * 
 * This library has more than 20 examples and it can be freely distributed using the MIT Free Software model. [Copyright (c) 2019 Ricardo Lima Caratti](https://pu2clr.github.io/SI4735/#mit-license).  
 * Contact: pu2clr@gmail.com
 * 
 * @details This library uses the I²C communication protocol and implements most of the functions offered by Si47XX (BROADCAST AM / FM / SW / LW RADIO RECEIVER) IC family from Silicon Labs. 
 * @details The main features of this library are listed below. 
 * @details 1. Open Source. It is free. You can use, copy, modify, merge, publish, distribute, sublicense, and/or sell copies of the Software. See [MIT License](https://pu2clr.github.io/SI4735/#mit-license) to know more.   
 * @details 2. Built Based on [Si47XX PROGRAMMING GUIDE](https://www.silabs.com/documents/public/application-notes/AN332.pdf).
 * @details 3. C++ Language and Object-oriented programming. You can easily extend the SI4735 class by adding more functionalities.
 * @details 4. Available on Arduino IDE (Manage Libraries).
 * @details 5. Cross-platform. You can compile and run this library on most of board available on Arduino IDE (Examples: ATtiny85, boards based on ATmega328 and ATmega-32u4, ATmega2560, 32 ARM Cortex, Arduino DUE, ESP32 and more). See [Boards where this library has been successfully tested](https://pu2clr.github.io/SI4735/#boards-where-this-library-has-been-successfully-tested).
 * @details 6. Simplifies projects based on SS4735-D60, SI4732-A10, SI4730-D60, and other SI473X devices;
 * @details 7. I²C communication and Automatic I²C bus address detection. 
 * @details 8. More than 120 functions implemented. You can customize almost every feature available on Si47XX family. 
 * @details 9. RDS support.
 * @details 10. SSB (Single Side Band) patch support (SI4735-D60 and SI4732-A10). 
 * @details 11. Digital Audio (__Attention__: Crystal and digital audio mode cannot be used at the same time).
 * @details 12. More than 20 example available.  See <https://github.com/pu2clr/SI4735/tree/master/examples><br>
 * 
 *  Some texts were extracted directly from the Silicon Labs documentation. The name of the Silicon Labs document and pages are described in the source code comments.
 * 
 * @see [General Documentation](https://pu2clr.github.io/SI4735/)
 * @see [Schematics](https://pu2clr.github.io/SI4735/extras/schematic/)
 * @see Si47XX PROGRAMMING GUIDE AN332 (REV 1.0): https://www.silabs.com/documents/public/application-notes/AN332.pdf
 * @see AN332 REV 0.8 UNIVERSAL PROGRAMMING GUIDE; AMENDMENT FOR SI4735-D60 SSB AND NBFM PATCHES
 * 
 * @author PU2CLR - Ricardo Lima Caratti 
 * @date  2019-2020
 * @copyright MIT Free Software model. See [Copyright (c) 2019 Ricardo Lima Caratti](https://pu2clr.github.io/SI4735/#mit-license). 
 */

#include "SI4735.h"

/**
 * @brief Construct a new SI4735::SI4735 
 * 
 * @details This class has a set of functions that can help you to build your receiver based on Si47XX IC family.
 * @details This library uses the I²C communication protocol and implements most of the functions offered by Si47XX (BROADCAST AM / FM / SW / LW RADIO RECEIVER) IC family from Silicon Labs. 
 * @details Currently you have more than 120 functions implemented to control the Si47XX devices. These functions are listed and documented here.
 * @details Some methods were implemented using inline resource. Inline methods are implemented in SI4735.h
 * 
 * IMPORTANT: According to Si47XX PROGRAMMING GUIDE; AN332 (REV 1.0); page 207, "For write operations, the system controller next 
 * sends a data byte on SDIO, which is captured by the device on rising edges of SCLK. The device acknowledges 
 * each data byte by driving SDIO low for one cycle on the next falling edge of SCLK. 
 * The system controller may write up to 8 data bytes in a single 2-wire transaction. 
 * The first byte is a command, and the next seven bytes are arguments. Writing more than 8 bytes results 
 * in unpredictable device behavior". So, If you are extending this library, consider that restriction presented earlier.
 */
SI4735::SI4735()
{
    // 1 = LSB and 2 = USB; 0 = AM, FM or WB
    currentSsbStatus = 0;
}

/** @defgroup group05 Deal with Interrupt and I2C bus */

/**
 * @ingroup group05 Interrupt
 * 
 * @brief Updates bits 6:0 of the status byte.
 * 
 * @details This command should be called after any command that sets the STCINT or RSQINT bits. 
 * @details When polling this command should be periodically called to monitor the STATUS byte, and when using interrupts, this command should be called after the interrupt is set to update the STATUS byte.
 * @details The CTS bit (and optional interrupt) is set when it is safe to send the next command.
 * 
 * @see Si47XX PROGRAMMING GUIDE; AN332 (REV 1.0); page 135 
 * @see si47x_status
 * @see waitToSend
 * 
 * @return si47x_status the bit data structure with the status response
 */
si47x_status SI4735::getInterruptStatus()
{
    si47x_status status;

    waitToSend();
    Wire.beginTransmission(deviceAddress);
    Wire.write(GET_INT_STATUS);
    Wire.endTransmission();

    Wire.requestFrom(deviceAddress, 1);
    status.raw = Wire.read();

    return status;
}
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
